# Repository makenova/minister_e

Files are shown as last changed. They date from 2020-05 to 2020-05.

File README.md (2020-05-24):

# Minister_E
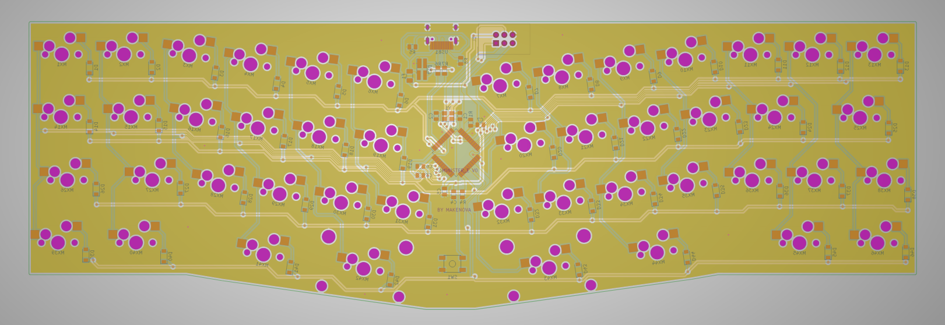
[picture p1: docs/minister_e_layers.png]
tracespace back


Minister_e is a hot swap 40% with a centered USB port and the layout of the prime_e V2.
I made this because the designer of the prime_e had no intention of making a hot swap version of the V2 PCB and I wanted one.

The step file can be found in the [docs](./docs) folder.

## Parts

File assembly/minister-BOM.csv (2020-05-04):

Designator | Quantity | Value | Footprint | LCSC Part #
C2, C1, | 2 | 22pF | 0805 | C1804
C3, | 1 | 1uF | 0805 | C28323
C4, C5, C6, | 3 | 0.1uF | 0805 | C49678
C7, | 1 | 10uF | 0805 | C15850
D20, D7, D43, D32, D21, D8, D33, D22, D9, D44, D34, D23, D10, D35, D24, D11, D36, D12, D45, D37, D25, D13, D46, D38, D30, D42, D5, D18, D29, D41, D4, D17, D28, D3, D16, D27, D40, D2, D15, D26, D39, D1, D14, D31, D6, D19, | 46 | D_Small | SOD-123 | C81598
D47, | 1 | PRTR5V0U2X | SOT-143 | C78442
F1, | 1 | Polyfuse_Small | 1206 | C151162
R4, R1, | 2 | 10k | 0805 | C17414
R5, R8, | 2 | 5.1k | 0805 | C27834
R6, R7, | 2 | 22 | 0805 | C17561
SW1, | 1 | SW_Push | SMD-SW-4_5.1x5.1x1.5 | C318884
U1, | 1 | ATmega32U4-AU | QFP-44_10.0x10.0x0.8P | C44854
Y1, | 1 | 16MHz | SMD-3225_4P | C13738

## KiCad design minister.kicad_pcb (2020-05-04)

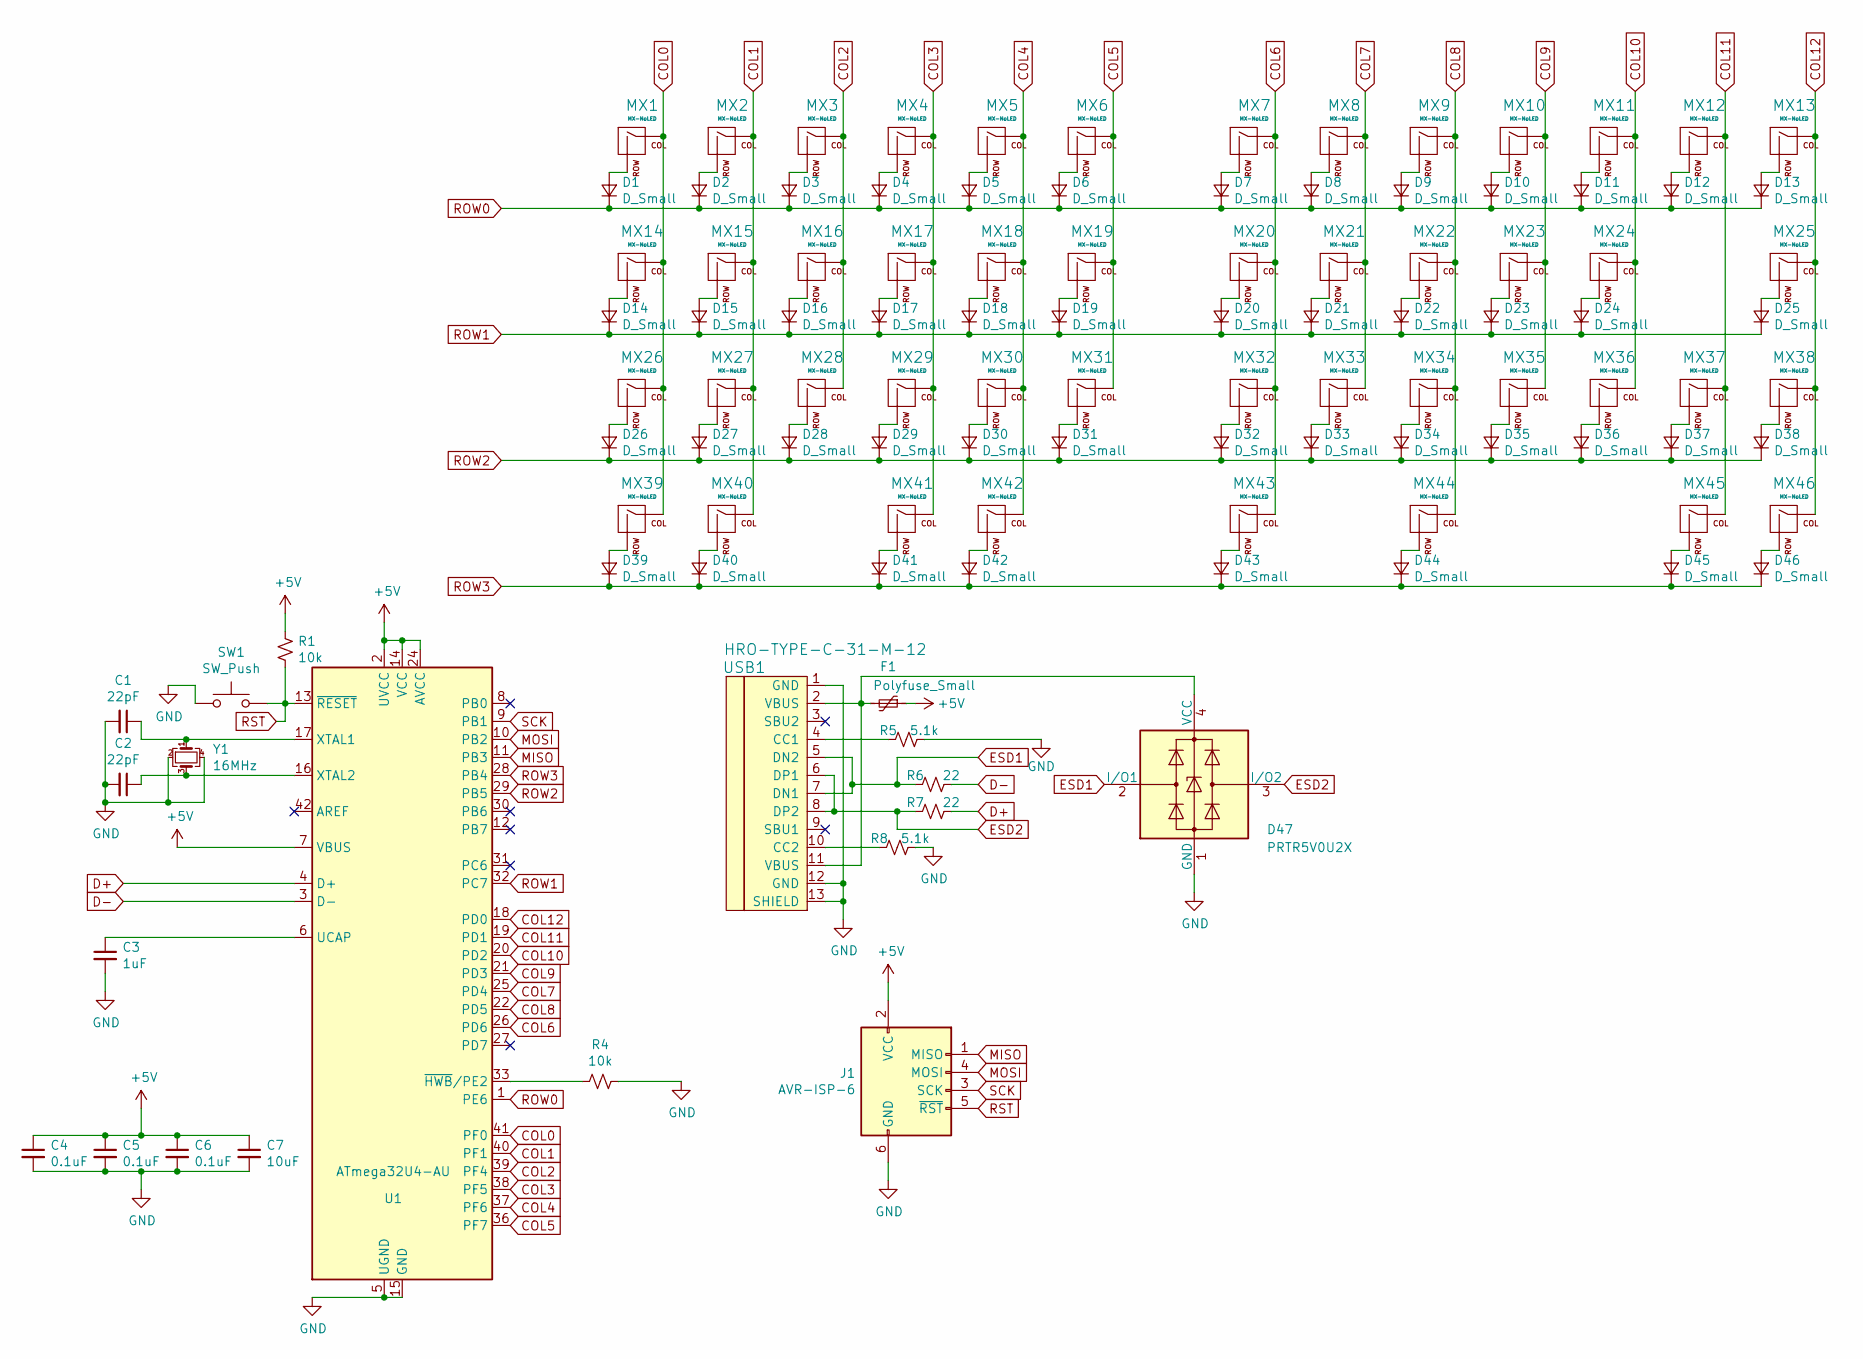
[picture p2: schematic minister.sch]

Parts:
C1, C2: 22pF; C_0805_2012Metric; LCSC C1804
C3: 1uF; C_0805_2012Metric; LCSC C28323
C4, C5, C6: 0.1uF; C_0805_2012Metric; LCSC C49678
C7: 10uF; C_0805_2012Metric; LCSC C307523
D1, D2, D3, D4, D5, D6, D7, D8, D9, D10, D11, D12, D13, D14, D15, D16, D17, D18, D19, D20, D21, D22, D23, D24, D25, D26, D27, D28, D29, D30, D31, D32, D33, D34, D35, D36, D37, D38, D39, D40, D41, D42, D43, D44, D45, D46: D_Small; D_SOD-123; LCSC C81598
D47: PRTR5V0U2X; SOT-143_Handsoldering; LCSC C78442
F1: Polyfuse_Small; Fuse_1206_3216Metric; LCSC C151162
J1: AVR-ISP-6; IDC-Header_2x03_P2.54mm_Vertical
MX1, MX2, MX3, MX4, MX5, MX6, MX7, MX8, MX9, MX10, MX11, MX12, MX13, MX15, MX16, MX17, MX18, MX19, MX20, MX21, MX22, MX23, MX24, MX27, MX28, MX29, MX30, MX31, MX32, MX33, MX34, MX35, MX36, MX37: MX-NoLED; MXOnly-1U-Hotswap
MX14, MX38, MX39, MX40, MX41, MX44, MX45, MX46: MX-NoLED; MXOnly-1.25U-Hotswap
MX25, MX26: MX-NoLED; MXOnly-1.75U-Hotswap
MX42: MX-NoLED; MXOnly-2U-Hotswap-ReversedStabilizers
MX43: MX-NoLED; MXOnly-2.25U-Hotswap-ReversedStabilizers
R1, R4: 10k; R_0805_2012Metric; LCSC C17414
R5, R8: 5.1k; R_0805_2012Metric; LCSC C27834
R6, R7: 22; R_0805_2012Metric; LCSC C17561
SW1: SW_Push; SKQG-1155865; LCSC C318884
U1: ATmega32U4-AU; TQFP-44_10x10mm_P0.8mm; LCSC C44854
USB1: HRO-TYPE-C-31-M-12; HRO-TYPE-C-31-M-12-HandSoldering
Y1: 16MHz; Crystal_SMD_3225-4Pin_3.2x2.5mm; LCSC C89379

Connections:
+5V: C4.1, C5.1, C6.1, C7.1, F1.1, J1.2 (VCC), R1.1, U1.2 (UVCC), U1.7 (VBUS), U1.14 (VCC), U1.24 (AVCC), U1.34 (VCC), U1.44 (AVCC)
COL0: MX1.1 (COL), MX14.1 (COL), MX26.1 (COL), MX39.1 (COL), U1.41 (PF0)
COL1: MX2.1 (COL), MX15.1 (COL), MX27.1 (COL), MX40.1 (COL), U1.40 (PF1)
COL2: MX3.1 (COL), MX16.1 (COL), MX28.1 (COL), U1.39 (PF4)
COL3: MX4.1 (COL), MX17.1 (COL), MX29.1 (COL), MX41.1 (COL), U1.38 (PF5)
COL4: MX5.1 (COL), MX18.1 (COL), MX30.1 (COL), MX42.1 (COL), U1.37 (PF6)
COL5: MX6.1 (COL), MX19.1 (COL), MX31.1 (COL), U1.36 (PF7)
COL6: MX7.1 (COL), MX20.1 (COL), MX32.1 (COL), MX43.1 (COL), U1.26 (PD6)
COL7: MX8.1 (COL), MX21.1 (COL), MX33.1 (COL), U1.25 (PD4)
COL8: MX9.1 (COL), MX22.1 (COL), MX34.1 (COL), MX44.1 (COL), U1.22 (PD5)
COL9: MX10.1 (COL), MX23.1 (COL), MX35.1 (COL), U1.21 (PD3)
COL10: MX11.1 (COL), MX24.1 (COL), MX36.1 (COL), U1.20 (PD2)
COL11: MX12.1 (COL), MX37.1 (COL), MX45.1 (COL), U1.19 (PD1)
COL12: MX13.1 (COL), MX25.1 (COL), MX38.1 (COL), MX46.1 (COL), U1.18 (PD0)
D+: R7.1, U1.4 (D+)
D-: R6.1, U1.3 (D-)
ESD1: D47.2 (I/O1), R6.2, USB1.5 (DN2), USB1.7 (DN1)
ESD2: D47.3 (I/O2), R7.2, USB1.6 (DP1), USB1.8 (DP2)
GND: C1.2, C2.2, C3.2, C4.2, C5.2, C6.2, C7.2, D47.1 (GND), J1.6 (GND), R4.1, R5.1, R8.1, SW1.1, U1.5 (UGND), U1.15 (GND), U1.23 (GND), U1.35 (GND), U1.43 (GND), USB1.1 (GND), USB1.12 (GND), USB1.13 (SHIELD), Y1.2, Y1.4
MISO: J1.1 (MISO), U1.11 (PB3)
MOSI: J1.4 (MOSI), U1.10 (PB2)
unnamed: C1.1, U1.17 (XTAL1), Y1.1
unnamed: C2.1, U1.16 (XTAL2), Y1.3
unnamed: C3.1, U1.6 (UCAP)
unnamed: D1.2 (A), MX1.2 (ROW)
unnamed: D2.2 (A), MX2.2 (ROW)
unnamed: D3.2 (A), MX3.2 (ROW)
unnamed: D4.2 (A), MX4.2 (ROW)
unnamed: D5.2 (A), MX5.2 (ROW)
unnamed: D6.2 (A), MX6.2 (ROW)
unnamed: D7.2 (A), MX7.2 (ROW)
unnamed: D8.2 (A), MX8.2 (ROW)
unnamed: D9.2 (A), MX9.2 (ROW)
unnamed: D10.2 (A), MX10.2 (ROW)
unnamed: D11.2 (A), MX11.2 (ROW)
unnamed: D12.2 (A), MX12.2 (ROW)
unnamed: D13.2 (A), MX13.2 (ROW)
unnamed: D14.2 (A), MX14.2 (ROW)
unnamed: D15.2 (A), MX15.2 (ROW)
unnamed: D16.2 (A), MX16.2 (ROW)
unnamed: D17.2 (A), MX17.2 (ROW)
unnamed: D18.2 (A), MX18.2 (ROW)
unnamed: D19.2 (A), MX19.2 (ROW)
unnamed: D20.2 (A), MX20.2 (ROW)
unnamed: D21.2 (A), MX21.2 (ROW)
unnamed: D22.2 (A), MX22.2 (ROW)
unnamed: D23.2 (A), MX23.2 (ROW)
unnamed: D24.2 (A), MX24.2 (ROW)
unnamed: D25.2 (A), MX25.2 (ROW)
unnamed: D26.2 (A), MX26.2 (ROW)
unnamed: D27.2 (A), MX27.2 (ROW)
unnamed: D28.2 (A), MX28.2 (ROW)
unnamed: D29.2 (A), MX29.2 (ROW)
unnamed: D30.2 (A), MX30.2 (ROW)
unnamed: D31.2 (A), MX31.2 (ROW)
unnamed: D32.2 (A), MX32.2 (ROW)
unnamed: D33.2 (A), MX33.2 (ROW)
unnamed: D34.2 (A), MX34.2 (ROW)
unnamed: D35.2 (A), MX35.2 (ROW)
unnamed: D36.2 (A), MX36.2 (ROW)
unnamed: D37.2 (A), MX37.2 (ROW)
unnamed: D38.2 (A), MX38.2 (ROW)
unnamed: D39.2 (A), MX39.2 (ROW)
unnamed: D40.2 (A), MX40.2 (ROW)
unnamed: D41.2 (A), MX41.2 (ROW)
unnamed: D42.2 (A), MX42.2 (ROW)
unnamed: D43.2 (A), MX43.2 (ROW)
unnamed: D44.2 (A), MX44.2 (ROW)
unnamed: D45.2 (A), MX45.2 (ROW)
unnamed: D46.2 (A), MX46.2 (ROW)
unnamed: D47.4 (VCC), F1.2, USB1.2 (VBUS), USB1.11 (VBUS)
unnamed: R4.2, U1.33 (~HWB~/PE2)
unnamed: R5.2, USB1.4 (CC1)
unnamed: R8.2, USB1.10 (CC2)
ROW0: D1.1 (K), D2.1 (K), D3.1 (K), D4.1 (K), D5.1 (K), D6.1 (K), D7.1 (K), D8.1 (K), D9.1 (K), D10.1 (K), D11.1 (K), D12.1 (K), D13.1 (K), U1.1 (PE6)
ROW1: D14.1 (K), D15.1 (K), D16.1 (K), D17.1 (K), D18.1 (K), D19.1 (K), D20.1 (K), D21.1 (K), D22.1 (K), D23.1 (K), D24.1 (K), D25.1 (K), U1.32 (PC7)
ROW2: D26.1 (K), D27.1 (K), D28.1 (K), D29.1 (K), D30.1 (K), D31.1 (K), D32.1 (K), D33.1 (K), D34.1 (K), D35.1 (K), D36.1 (K), D37.1 (K), D38.1 (K), U1.29 (PB5)
ROW3: D39.1 (K), D40.1 (K), D41.1 (K), D42.1 (K), D43.1 (K), D44.1 (K), D45.1 (K), D46.1 (K), U1.28 (PB4)
RST: J1.5 (~RST), R1.2, SW1.2, U1.13 (~RESET)
SCK: J1.3 (SCK), U1.9 (PB1)

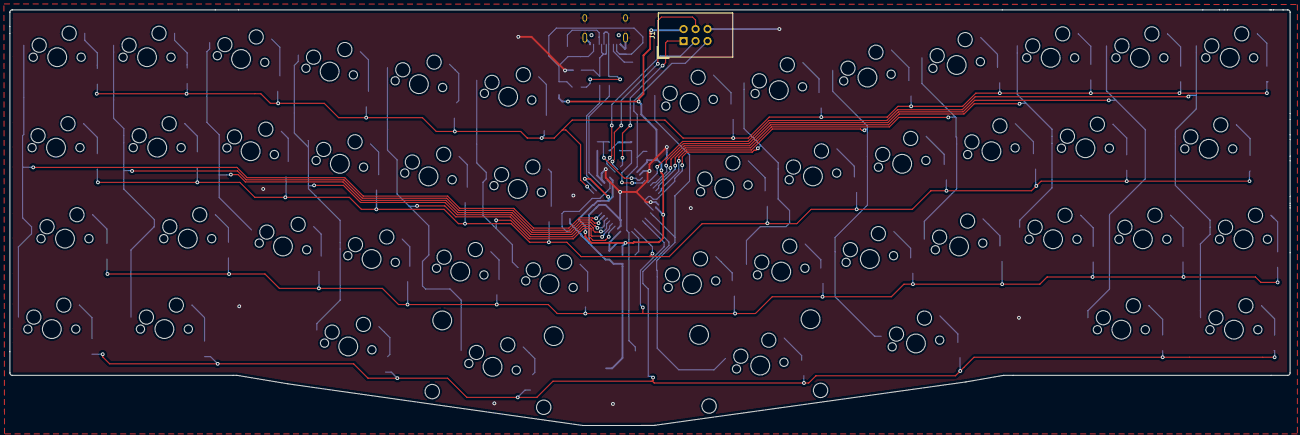
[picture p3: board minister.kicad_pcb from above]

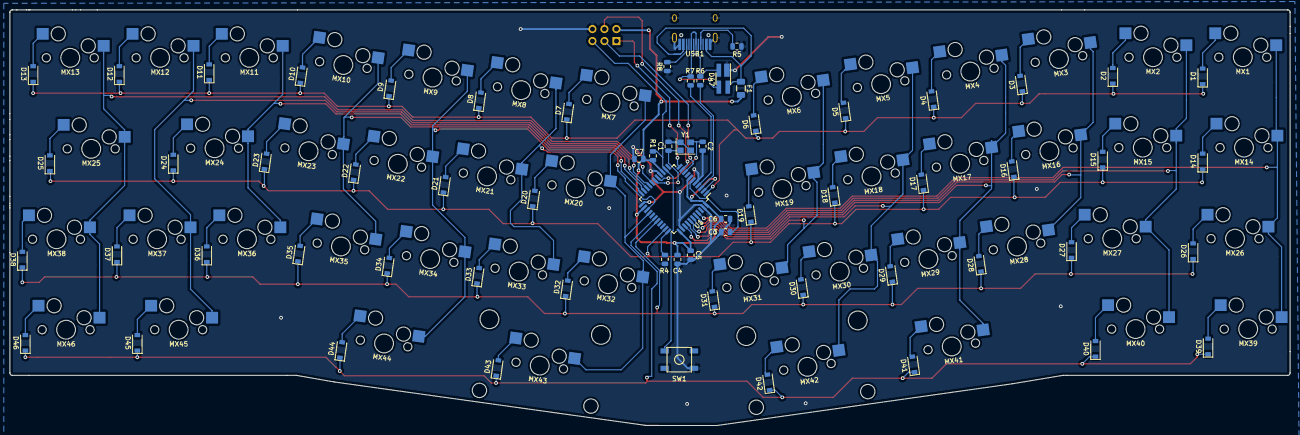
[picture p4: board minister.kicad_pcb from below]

Board: 2 copper layers, 271.5 x 88.1 mm, 112 parts (65 on the bottom side), 80 nets.

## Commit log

2020-04-12 make it so
    [minister.kicad_pcb, minister.sch]
2020-04-12 add footprint libraries
2020-04-12 create mcu schematic
2020-04-12 schematic complete
    [minister.sch]
2020-04-12 Assign Footprints
    [minister.sch]
2020-04-12 update footprints
    [minister.sch]
2020-04-12 rough component placement on pcb
    [minister.kicad_pcb]
2020-04-12 move surface mount componets to bottom with 'F'
    [minister.kicad_pcb]
2020-04-12 rearrange components
    [minister.sch]
2020-04-12 import prime_e edge cuts
    [minister.kicad_pcb]
2020-04-12 everything laid out
    [minister.kicad_pcb]
2020-04-12 use shaped edge cuts
    [minister.kicad_pcb]
2020-04-13 start routing
    [minister.kicad_pcb]
2020-04-17 more routing
    [minister.kicad_pcb, minister.sch]
2020-04-18 all routing done? except for gnd
    [minister.kicad_pcb]
2020-04-19 add ground fill and run drc
    [minister.kicad_pcb]
2020-04-19 fix drc errors
    [minister.kicad_pcb]
2020-04-20 replace usb and generate output files
    [minister-B_Cu.gbr, minister-B_Mask.gbr, minister-B_SilkS.gbr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]
2020-04-20 clean up slik screen
    [minister-B_Cu.gbr, minister-B_Mask.gbr, minister-B_SilkS.gbr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]
2020-04-20 not sure
    [minister.kicad_pcb, minister.sch]
2020-05-03 add isp
    [minister.kicad_pcb, minister.sch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]
2020-05-03 clean up and touch up pcb
    [minister.sch]
2020-05-04 submit for production
    generate gerbers and drill files
    generate bom and placement file
    update some parts
    [minister-BOM.csv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]
2020-05-14 add output of tracespace
